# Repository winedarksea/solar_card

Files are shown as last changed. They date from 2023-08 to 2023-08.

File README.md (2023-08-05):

# Solar-Powered LED Flashlight Business Card
created by Colin Catlin, 2023

A business card that can also double as a decently powerful, RGB flashlight, complete with solar charging. Built for business, ready for the apocalypse.

Built in KiCAD V6, opens with V7 and possibly later (those haven't been released as of this release).

GPLv3 licensed so that you can freely go and make variations with your own name. Or run around handling out ones with my name while pretending to be me? Please only do the latter if you are very charming and attractive.

I have had this made and assembled by JLCPCB, as you'll notice. Only the back side was assembled by them. 
Additionally there is a PTC reset fuse which is marked with a 0 ohm resistor, size 1812. 
You can use the resistor if you don't want the reset fuse, it isn't necessary but adds a little extra safety.

For that fuse, I chose Bourns MF-MSMF020-2 PTC RESET FUSE 30V 200MA 1812 and hand-assembled it with hot air. It's a relatively big part, easy to solder.

I also hand assembled the solar panel and the LEDs on the front side. Choosing LEDs is fun. I tried to size the pad so that that most 3030 or 2835 LEDs would work. 
I found that it even works with those that have a three part footprint (one of which can safely be connected to return). 

The giant vias are for allowing hot air from the bottom to reach solder paste on the other side for attaching the solar panel. It works. Actually these vias are bigger than really necessary, going down a bit smaller would work well and be more discrete, but not too small, 0.3 mm was definitely too small.

The idea here with three LEDs is that you can choose three different colors, red, green, and blue, and then mix them with potentiometers to make 'any' color. It works! 
But for more flashlight purposes you can just choose the most efficient white-ish colors (for still some fun, choose a low kelvin and high kelvin color mix, so you still can get blue-ish and yellow-ish). I had thought the Samsung ultra efficient LEDs would be best, and they do work well, but for the best flashlight I found the narrowest possible viewing angle made the most impact (since there is no light focusing reflector here like a normal flashlight). One I tried that worked well was the "LED Lighting OSLON® SSL 80 White, Cool 6500K 2.85V 350mA 80° 1212 (3030 Metric)" - the most important part is that 80 degree viewing angle.

The idea here was the undervoltage protection would be afforded by the dropout voltage of the LEDs (they stop working with too little voltage, that's good here). Unfortunately I have found that green LEDs, in particular, can run down to a lower voltage than their datasheet suggests. Check the minimum voltage of LEDs manually if aiming for optimal battery protection.

Please see my blogpost for more details: 
https://syllepsis.live/2023/08/05/the-solar-powered-business-card/

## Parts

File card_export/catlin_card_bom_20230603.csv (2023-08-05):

Designator | Comment | Footprint | JCLPCB Part #
BT1, | Batt LIR2450 | Battery:BatteryHolder_Keystone_3008_1x2450 | C964845
C1, C2, C3, | 1 uF | Capacitor_SMD:C_0805_2012Metric_Pad1.18x1.45mm_HandSolder | C28323
D1, | R_LED | PowerIC:LED_SMD3030 | C1322324
D2, | G_LED | PowerIC:LED_SMD3030 | C1322325
D3, | B_LED | PowerIC:LED_SMD3030 | C440449
D4, | SS54 | Diode_SMD:D_SMA_Handsoldering | C22452
D5, | TVS | Diode_SMD:D_SOD-123 | C2990493
J1, | pinhead | Connector_PinHeader_2.54mm:PinHeader_1x02_P2.54mm_Vertical
R1, R4, R6, | 100Ω | Resistor_SMD:R_1206_3216Metric | C17901
R2, R3, R5, | 300Ω | Resistor_SMD:R_1206_3216Metric | C17887
R7, | 1kΩ | Resistor_SMD:R_0805_2012Metric_Pad1.20x1.40mm_HandSolder | C17513
R8, | 2.4kΩ | Resistor_SMD:R_0805_2012Metric_Pad1.20x1.40mm_HandSolder | C17526
RV1, RV2, RV3, | Pot 5kΩ 0.25W | Potentiometer_SMD:Potentiometer_Bourns_3314G_Vertical | C719180
SC1, | Solar_Cell | Resistor_SMD:R_4020_10251Metric | SM141K10LV
SW1, | SW_SPDT | Button_Switch_SMD:SW_SPDT_PCM12 | C128955
TH1, | Thermistor_PTC | Resistor_SMD:R_1812_4532Metric_Pad1.30x3.40mm_HandSolder
TP1, TP4, | TestPoint | TestPoint:TestPoint_Pad_2.0x2.0mm
TP2, TP5, | TP | TestPoint:TestPoint_Pad_4.0x4.0mm
TP3, | TP | TestPoint:TestPoint_Pad_1.0x1.0mm
U1, | AP2210K-ADJ | Package_TO_SOT_SMD:SOT-23-5 | C507874

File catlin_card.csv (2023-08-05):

Source: | /Users/colincatlin/Documents/catlin_card/catlin_card.kicad_sch
Date: | Saturday, June 03, 2023 at 09:45:14 PM
Tool: | Eeschema (6.0.2-0)
Generator: | /Applications/KiCad/KiCad.app/Contents/SharedSupport/plugins/bom_csv_grouped_by_value_with_fp.py
Component Count: | 30
Ref | Qnty | Value | Cmp name | Footprint | Description | Vendor
BT1, | 1 | Batt LIR2450 | Battery | Battery:BatteryHolder_Keystone_3008_1x2450 | Multiple-cell battery | C964845
C1, C2, C3, | 3 | 1 uF | C_Small | Capacitor_SMD:C_0805_2012Metric_Pad1.18x1.45mm_HandSolder | Unpolarized capacitor, small symbol | C28323
D1, | 1 | R_LED | LED | PowerIC:LED_SMD3030 | Light emitting diode | C1322324
D2, | 1 | G_LED | LED | PowerIC:LED_SMD3030 | Light emitting diode | C1322325
D3, | 1 | B_LED | LED | PowerIC:LED_SMD3030 | Light emitting diode | C440449
D4, | 1 | SS54 | D_Schottky | Diode_SMD:D_SMA_Handsoldering | Schottky diode | C22452
D5, | 1 | TVS | D_Zener | Diode_SMD:D_SOD-123 | Zener diode | C2990493
J1, | 1 | pinhead | Conn_01x02 | Connector_PinHeader_2.54mm:PinHeader_1x02_P2.54mm_Vertical | Generic connector, single row, 01x02, script generated (kicad-library-utils/schlib/autogen/connector/)
R1, R4, R6, | 3 | 100Ω | R_Small | Resistor_SMD:R_1206_3216Metric | Resistor, small symbol | C17901
R2, R3, R5, | 3 | 300Ω | R_Small | Resistor_SMD:R_1206_3216Metric | Resistor, small symbol | C17887
R7, | 1 | 1kΩ | R_Small | Resistor_SMD:R_0805_2012Metric_Pad1.20x1.40mm_HandSolder | Resistor, small symbol | C17513
R8, | 1 | 2.4kΩ | R_Small | Resistor_SMD:R_0805_2012Metric_Pad1.20x1.40mm_HandSolder | Resistor, small symbol | C17526
RV1, RV2, RV3, | 3 | Pot 5kΩ 0.25W | R_Potentiometer | Potentiometer_SMD:Potentiometer_Bourns_3314G_Vertical | Potentiometer | C719180
SC1, | 1 | Solar_Cell | Solar_Cell | Resistor_SMD:R_4020_10251Metric | Single solar cell | SM141K10LV
SW1, | 1 | SW_SPDT | SW_SPDT | Button_Switch_SMD:SW_SPDT_PCM12 | Switch, single pole double throw | C128955
TH1, | 1 | Thermistor_PTC | Thermistor_PTC | Resistor_SMD:R_1812_4532Metric_Pad1.30x3.40mm_HandSolder | Temperature dependent resistor, positive temperature coefficient
TP1, TP4, | 2 | TestPoint | TestPoint | TestPoint:TestPoint_Pad_2.0x2.0mm | test point
TP2, TP5, | 2 | TP | TestPoint | TestPoint:TestPoint_Pad_4.0x4.0mm | test point
TP3, | 1 | TP | TestPoint | TestPoint:TestPoint_Pad_1.0x1.0mm | test point
U1, | 1 | AP2210K-ADJ | AP2204K-ADJ | Package_TO_SOT_SMD:SOT-23-5 | 150mA low dropout adjustable linear regulator, wide input voltage range, SOT-23-5 package | C507874

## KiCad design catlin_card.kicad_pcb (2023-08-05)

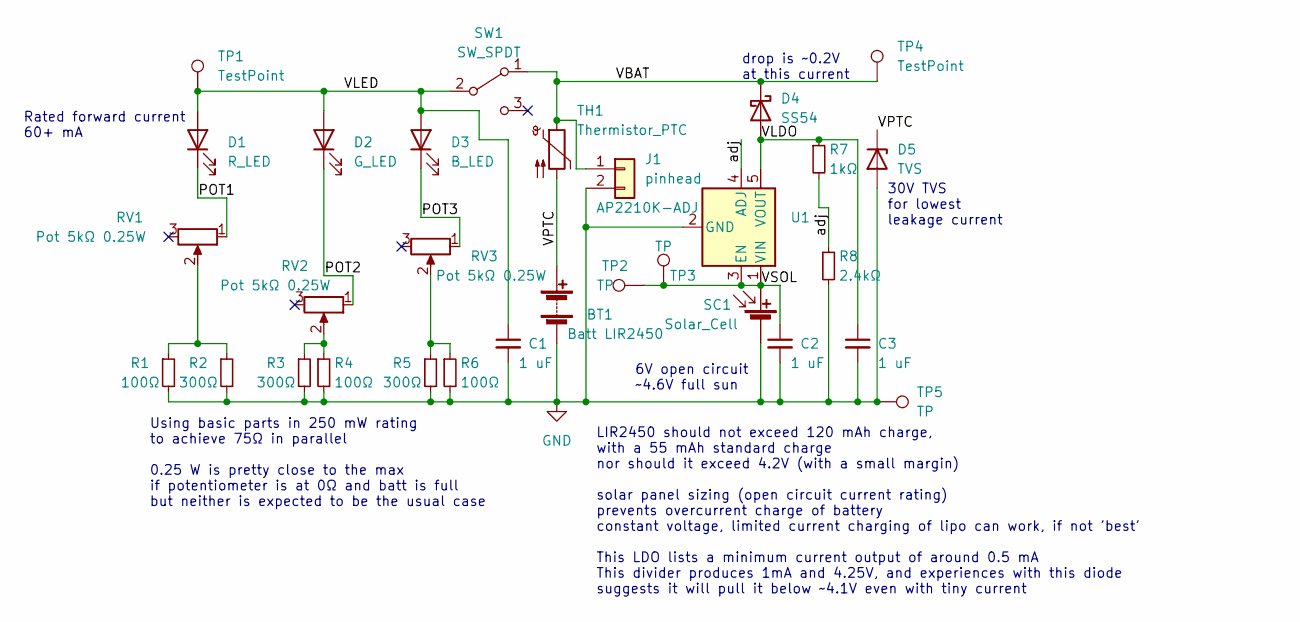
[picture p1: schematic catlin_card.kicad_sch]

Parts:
BT1: Batt LIR2450; BatteryHolder_Keystone_3008_1x2450
C1, C2, C3: 1 uF; C_0805_2012Metric_Pad1.18x1.45mm_HandSolder
D1: R_LED; LED_SMD3030
D2: G_LED; LED_SMD3030
D3: B_LED; LED_SMD3030
D4: SS54; D_SMA_Handsoldering
D5: TVS; D_SOD-123
J1: pinhead; PinHeader_1x02_P2.54mm_Vertical
R1, R4, R6: 100Ω; R_1206_3216Metric
R2, R3, R5: 300Ω; R_1206_3216Metric
R7: 1kΩ; R_0805_2012Metric_Pad1.20x1.40mm_HandSolder
R8: 2.4kΩ; R_0805_2012Metric_Pad1.20x1.40mm_HandSolder
RV1, RV2, RV3: Pot 5kΩ 0.25W; Potentiometer_Bourns_3314G_Vertical
SC1: Solar_Cell; R_4020_10251Metric
SW1: SW_SPDT; SW_SPDT_PCM12
TH1: Thermistor_PTC; R_1812_4532Metric_Pad1.30x3.40mm_HandSolder
TP1, TP4: TestPoint; TestPoint_Pad_2.0x2.0mm
TP2, TP5: TP; TestPoint_Pad_4.0x4.0mm
TP3: TP; TestPoint_Pad_1.0x1.0mm
U1: AP2210K-ADJ; SOT-23-5

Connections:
/POT1: D1.1 (K), RV1.1
/POT2: D2.1 (K), RV2.1
/POT3: D3.1 (K), RV3.1
/VBAT: D4.1 (K), J1.1, SW1.1 (A), TH1.1, TP4.1
/VLDO: C3.1, D4.2 (A), R7.1, U1.5 (VOUT)
/VLED: C1.1, D1.2 (A), D2.2 (A), D3.2 (A), SW1.2 (B), TP1.1
/VPTC: BT1.1 (+), D5.1 (K), TH1.2
/VSOL: C2.1, SC1.1 (+), TP2.1, TP3.1, U1.1 (VIN), U1.3 (EN)
/adj: R7.2, R8.1, U1.4 (ADJ)
GND: BT1.2 (-), C1.2, C2.2, C3.2, D5.2 (A), J1.2, R1.2, R2.2, R3.2, R4.2, R5.2, R6.2, R8.2, SC1.2 (-), TP5.1, U1.2 (GND)
unnamed: R1.1, R2.1, RV1.2
unnamed: R3.1, R4.1, RV2.2
unnamed: R5.1, R6.1, RV3.2

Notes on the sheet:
Rated forward current 60+ mA
LIR2450 should not exceed 120 mAh charge, with a 55 mAh standard charge nor should it exceed 4.2V (with a small margin) solar panel sizing (open circuit current rating) prevents overcurrent charge of battery constant voltage, limited current charging of lipo can work, if not 'best' This LDO lists a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
6V open circuit ~4.6V full sun
30V TVS for lowest leakage current
Using basic parts in 250 mW rating to achieve 75Ω in parallel 0.25 W is pretty close to the max if potentiometer is at 0Ω and batt is full but neither is expected to be the usual case
drop is ~0.2V at this current

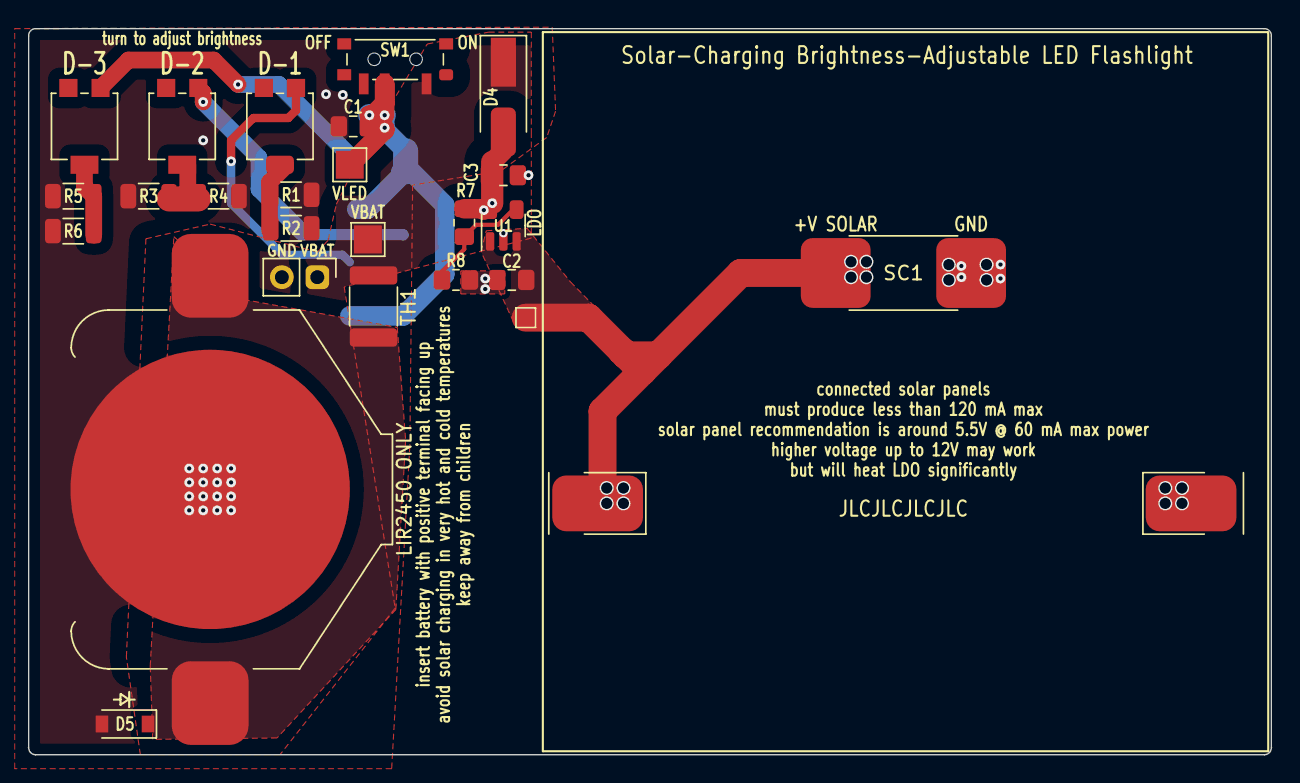
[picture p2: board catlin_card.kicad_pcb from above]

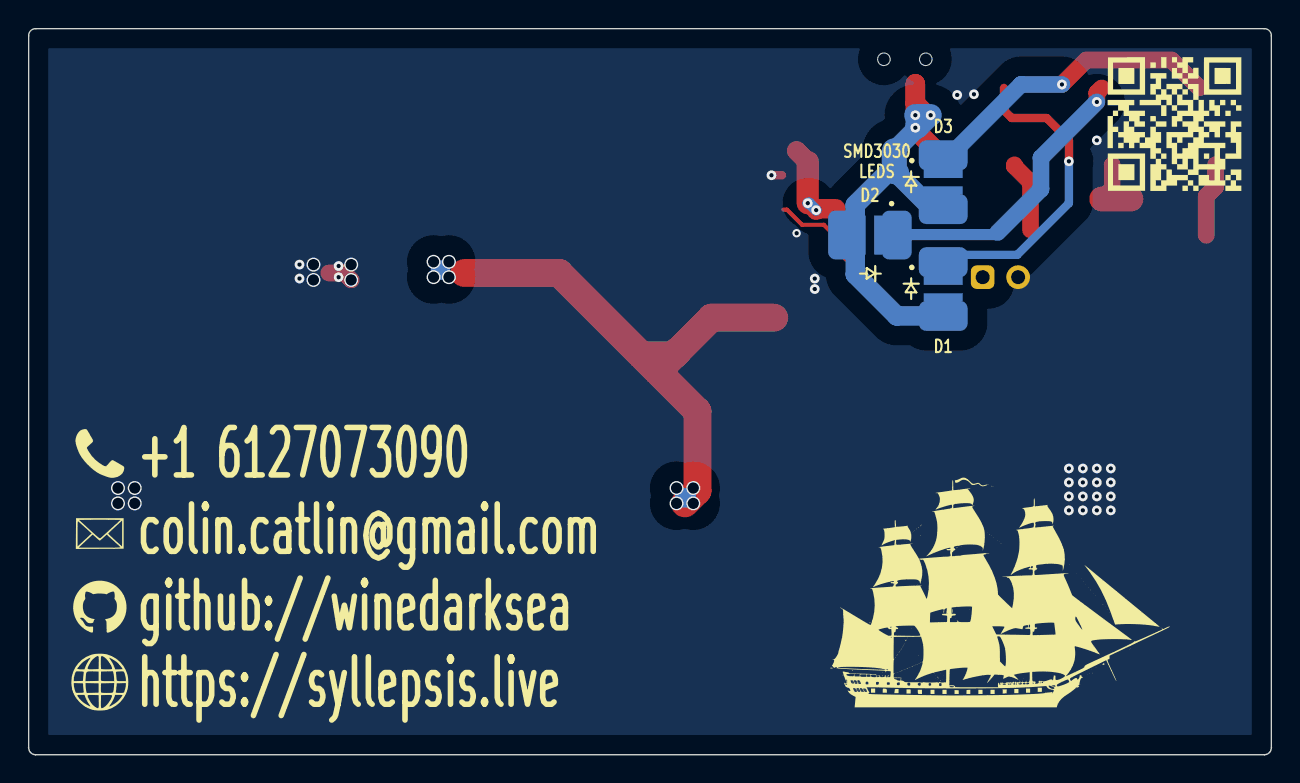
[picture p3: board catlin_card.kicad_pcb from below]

Board: 2 copper layers, 89.0 x 52.0 mm, 30 parts (3 on the bottom side), 13 nets.
